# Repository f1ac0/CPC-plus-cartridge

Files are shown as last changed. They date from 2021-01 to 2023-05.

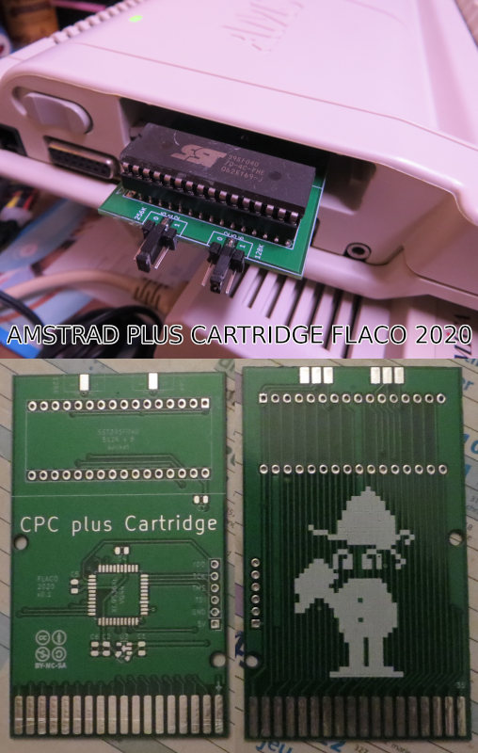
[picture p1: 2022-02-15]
CPC plus Cartridge FLACO 2020.JPG

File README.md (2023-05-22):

# CPC-plus-cartridge
In this repository you will find different PCB designs and code to make a CPC-plus cartridge. The ACID chip is implemented inside a XC9536XL CPLD using the equations published by octoate : https://www.octoate.de/articles/acid-verilog-code/

Facts about this project :
- The ZIF version has a ZIF socket for DIP32 ROM SST39SF040 or W29C040, and is longer than standard cartridges
- the PLCC version can be used with PLCC SST39SF040 ROMs and its size is more standard
- They both have jumpers to select 128k, 256k or 512K cartridge ROM banks

# Disclaimer
This is a hobbyist project, it comes with no warranty and no support. Also remember that the Amstrad machines are about 30 years old and may fail because of such hardware expansions.

I publish my work under the CC-BY-NC-SA license.

If you find it useful and want to reward me : I am always looking for Amiga/Amstrad CPC hardware to repair and hack, please contact me.

# BOM
- 1x XC9536XL CPLD
- 1x DIP32/PLCC32 ROM SST39SF040 or W29C040 and appropriate socket
- 1x 3.3v LDO, either SPX3819M5-L-3-3 or XC6206P332MR
- 2x 1uF (or more) 0805 capacitors
- 4x 100nF 0805 capacitors

# Making it
Check for shorts at least between 5V, 3.3V, and GND traces before applying power !

The programming port does not need to be soldered since it needs to be programmed just once : you can just hold it in place during the few seconds required for programming.

CPLD code is generated and built into xsvf using Xilinx ISE 14.7 IDE then iMPACT. "Macrocell power setting" can be "Low" an "Slew rate" to "Slow".

There are several methods to program the XC9536XL. I personally use xsvfduino : https://github.com/wschutzer/xsvfduino

Check the alignment between the cartridge pads and connector pads inside the CPC when installing it for the first time.

# Using it
- Burn the ROM images and install the ROM. Do not burn .cpr files directly, they need to be first converted using for example "CPRTools".
- Choose the ROM to use and its size using the jumpers :
  - 512k = both jumpers vertical
  - 256k = "128" jumper vertical and "256" to select 0 or 1
  - 128k = both jumpers to select 0 or 1
- Enjoy

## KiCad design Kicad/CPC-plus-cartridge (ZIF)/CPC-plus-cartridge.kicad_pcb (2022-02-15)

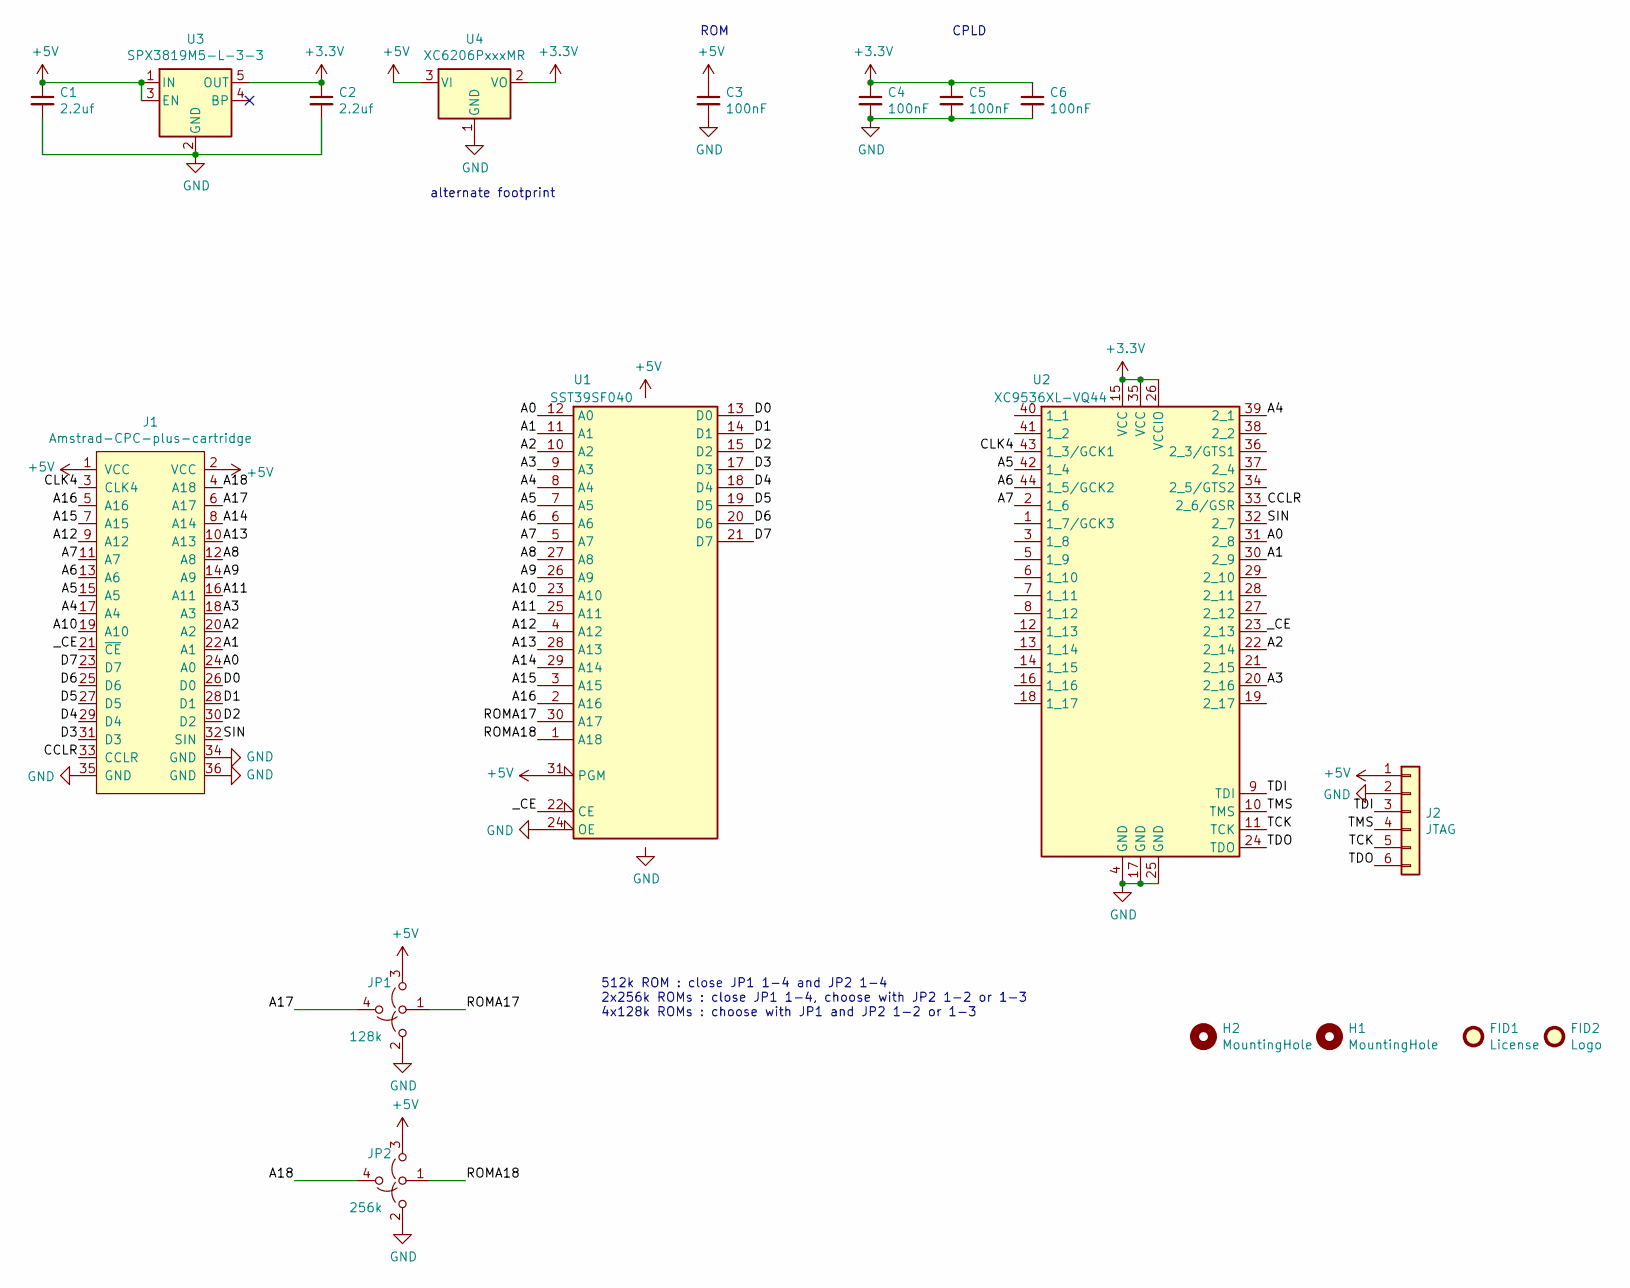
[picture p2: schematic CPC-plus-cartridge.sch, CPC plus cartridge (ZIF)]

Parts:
C1, C2: 2.2uf; C_0805_2012Metric
C3, C4, C5, C6: 100nF; C_0805_2012Metric
FID1: License; CC_BY_NC_SA_square_silkscreen
FID2: Logo; PIC_Cassepanards_GS
H1, H2: MountingHole; MountingHole_3mm
J1: Amstrad-CPC-plus-cartridge
J2: JTAG; PinHeader_1x06_P2.54mm_Vertical
JP1: 128k; Jumper_4_SPTT_P2.54mm_Edgemount
JP2: 256k; Jumper_4_SPTT_P2.54mm_Edgemount
U1: SST39SF040; DIP-32_W15.24mm_Socket_1mm
U2: XC9536XL-VQ44; LQFP-44_10x10mm_P0.8mm
U3: SPX3819M5-L-3-3; SOT-23-5
U4: XC6206PxxxMR; SOT-23

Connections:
+3V3: C2.1, C4.1, C5.1, C6.1, U2.15 (VCC), U2.26 (VCCIO), U2.35 (VCC), U3.5 (OUT), U4.2 (VO)
+5V: C1.1, C3.1, J1.1 (VCC), J1.2 (VCC), J2.1, JP1.3 (B), JP2.3 (B), U1.31 (PGM), U1.32 (VCC), U3.1 (IN), U3.3 (EN), U4.3 (VI)
/A0: J1.24 (A0), U1.12 (A0), U2.31 (2_8)
/A1: J1.22 (A1), U1.11 (A1), U2.30 (2_9)
/A2: J1.20 (A2), U1.10 (A2), U2.22 (2_14)
/A3: J1.18 (A3), U1.9 (A3), U2.20 (2_16)
/A4: J1.17 (A4), U1.8 (A4), U2.39 (2_1)
/A5: J1.15 (A5), U1.7 (A5), U2.42 (1_4)
/A6: J1.13 (A6), U1.6 (A6), U2.44 (1_5/GCK2)
/A7: J1.11 (A7), U1.5 (A7), U2.2 (1_6)
/A8: J1.12 (A8), U1.27 (A8)
/A9: J1.14 (A9), U1.26 (A9)
/A10: J1.19 (A10), U1.23 (A10)
/A11: J1.16 (A11), U1.25 (A11)
/A12: J1.9 (A12), U1.4 (A12)
/A13: J1.10 (A13), U1.28 (A13)
/A14: J1.8 (A14), U1.29 (A14)
/A15: J1.7 (A15), U1.3 (A15)
/A16: J1.5 (A16), U1.2 (A16)
/A17: J1.6 (A17), JP1.4 (D)
/A18: J1.4 (A18), JP2.4 (D)
/CCLR: J1.33 (CCLR), U2.33 (2_6/GSR)
/CLK4: J1.3 (CLK4), U2.43 (1_3/GCK1)
/D0: J1.26 (D0), U1.13 (D0)
/D1: J1.28 (D1), U1.14 (D1)
/D2: J1.30 (D2), U1.15 (D2)
/D3: J1.31 (D3), U1.17 (D3)
/D4: J1.29 (D4), U1.18 (D4)
/D5: J1.27 (D5), U1.19 (D5)
/D6: J1.25 (D6), U1.20 (D6)
/D7: J1.23 (D7), U1.21 (D7)
/ROMA17: JP1.1 (A), U1.30 (A17)
/ROMA18: JP2.1 (A), U1.1 (A18)
/SIN: J1.32 (SIN), U2.32 (2_7)
/TCK: J2.5, U2.11 (TCK)
/TDI: J2.3, U2.9 (TDI)
/TDO: J2.6, U2.24 (TDO)
/TMS: J2.4, U2.10 (TMS)
/_CE: J1.21 (~CE~), U1.22 (CE), U2.23 (2_13)
GND: C1.2, C2.2, C3.2, C4.2, C5.2, C6.2, J1.34 (GND), J1.35 (GND), J1.36 (GND), J2.2, JP1.2 (B), JP2.2 (B), U1.16 (GND), U1.24 (OE), U2.4 (GND), U2.17 (GND), U2.25 (GND), U3.2 (GND), U4.1 (GND)

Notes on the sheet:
ROM
CPLD
alternate footprint
512k ROM : close JP1 1-4 and JP2 1-4 2x256k ROMs : close JP1 1-4, choose with JP2 1-2 or 1-3 4x128k ROMs : choose with JP1 and JP2 1-2 or 1-3

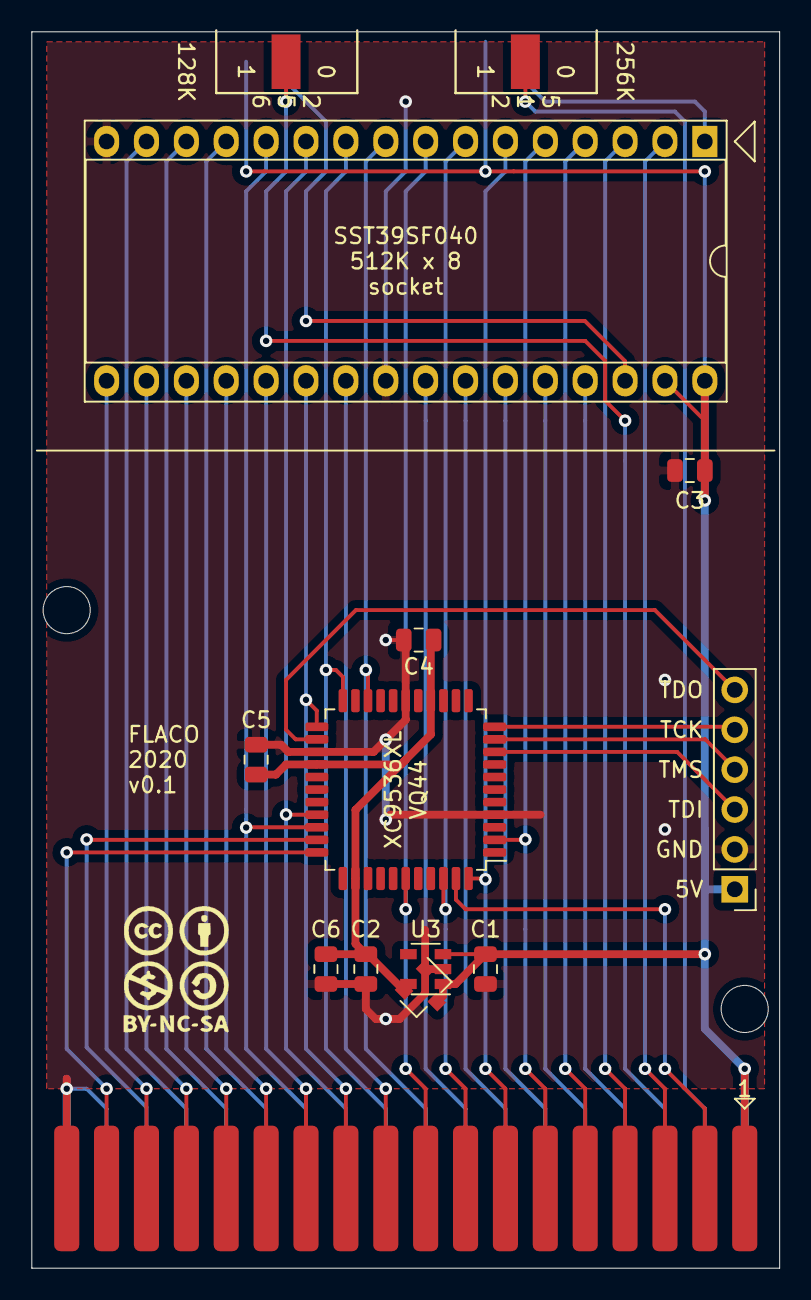
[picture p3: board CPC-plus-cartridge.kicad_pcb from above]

Board: 2 copper layers, 47.6 x 78.7 mm, 18 parts (1 on the bottom side), 40 nets.

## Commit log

2021-01-19 Respository init with KiCAD files, CPLD, Readme and License
    [CPC-plus-cartridge.kicad_pcb, CPC-plus-cartridge.sch]
2021-03-06 New KiCAD design for PLCC EPROM
    [CPC-plus-cartridge.kicad_pcb, CPC-plus-cartridge.sch]
2022-02-15 Photo, InteractiveHtmlBom and README
    [CPC-plus-cartridge.kicad_pcb, CPC-plus-cartridge.sch]

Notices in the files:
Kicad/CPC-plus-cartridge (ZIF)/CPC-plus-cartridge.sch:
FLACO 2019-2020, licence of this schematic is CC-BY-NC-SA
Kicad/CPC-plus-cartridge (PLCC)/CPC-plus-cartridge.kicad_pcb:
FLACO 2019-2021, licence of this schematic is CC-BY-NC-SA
